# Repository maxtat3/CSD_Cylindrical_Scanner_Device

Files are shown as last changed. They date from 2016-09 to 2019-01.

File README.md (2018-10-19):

# Cylindrical Scanner Device (CSD)
This electronic-mechanical device for research of processes in the activation of surfaces by diffusion welding and soldering cylinder samples in a vacuum. It is used for scientific research.
Named: Cylindrical Scanner Device (CSD) or Surface Activation Scanner (SAC) .
You can [view photo](https://drive.google.com/folderview?id=0B9YGrJoTVMatWHJlU2hkQTU4MW8&usp=sharing) when debug this device.

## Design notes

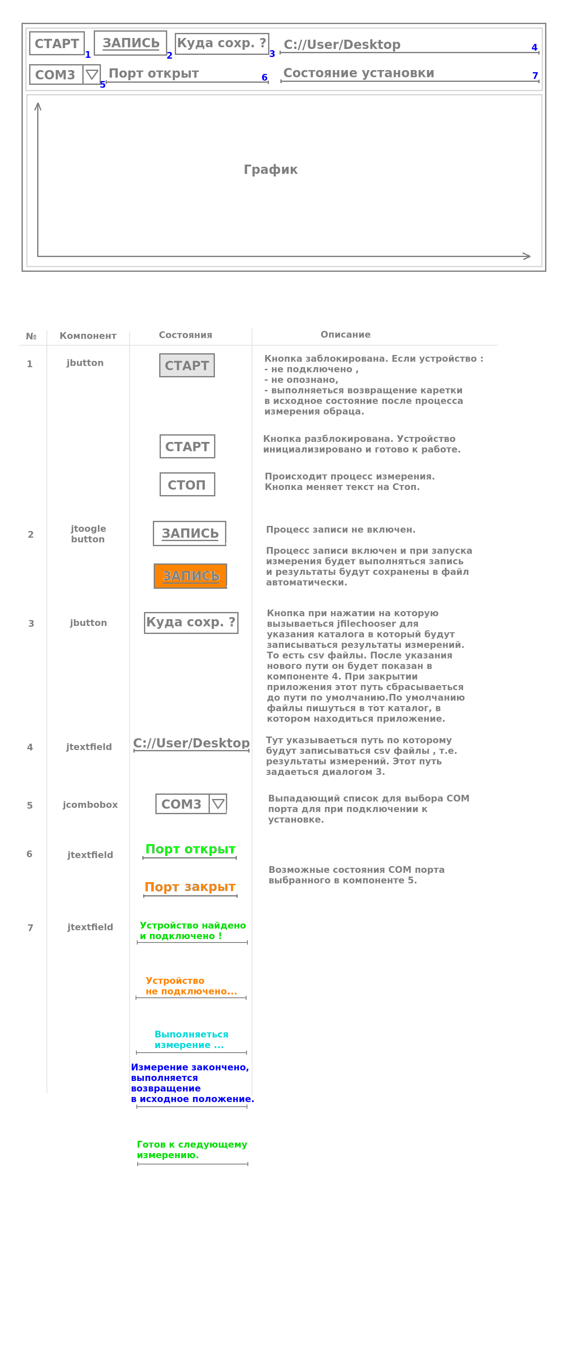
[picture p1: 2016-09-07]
etc/UI_mockup.png

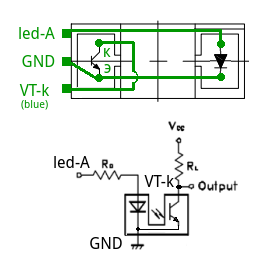
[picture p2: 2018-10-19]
etc/opto-interrupter.png

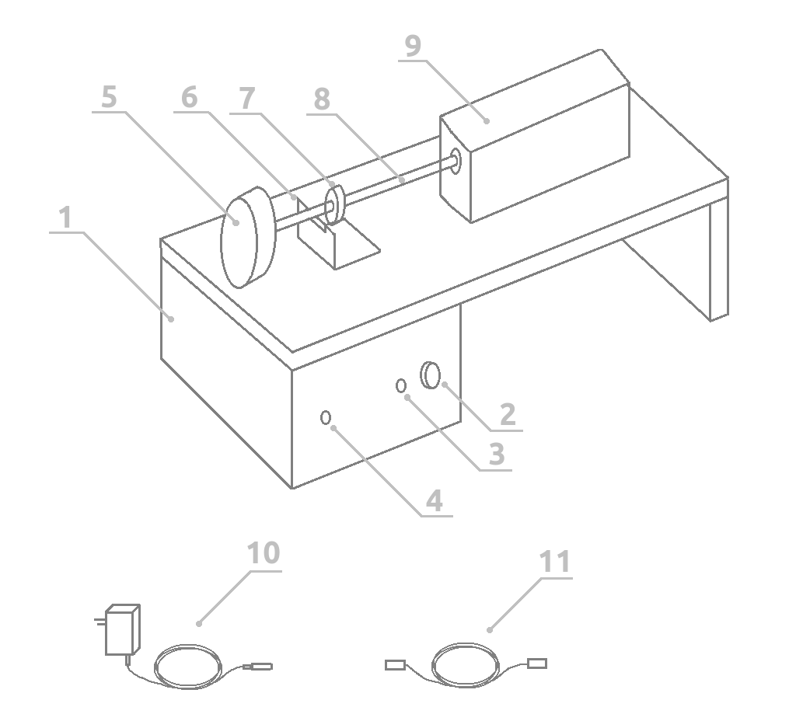
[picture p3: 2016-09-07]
etc/эскиз установки.png

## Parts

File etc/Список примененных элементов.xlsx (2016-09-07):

Идентификатор | Элемент | Корпус | Количество | Номинал | Цена за шт.(грн.) | Кол-во * шт (грн.)
1 | IC2 | TQFP32 | 1 | ATMEGA8A-AU | 35 | 35
2 | Q3,Q2,Q4,Q1 | to220_std | 4 | KT829 | 14 | 56
3 | D1,D2 | sod87 | 2 | 3V6 | 0.38 | 0.76
4 | RV2 | RV2 | 1 | 33k | 1.6 | 1.6
5 | RV1 | RV2 | 1 | 1k | 1.6 | 1.6
6 | RV3 | RV2 | 1 | 10k | 1.5 | 1.5
7 | R15,R14,R9,R16,R13,R12 | r_0805 | 6 | 510 | 0.1 | 0.6
8 | R17,R10,R2,R11 | r_0805 | 4 | 10k | 0.1 | 0.4
9 | R3 | r_0805 | 1 | 1.5k | 0.1 | 0.1
10 | R5,R4 | r_0805 | 2 | 68 | 0.1 | 0.2
11 | R6 | r_0805 | 1 | 300 | 0.1 | 0.1
12 | R8,R7 | r_0805 | 2 | 310 | 0.1 | 0.2
13 | R1 | r_0805 | 1 | 910 | 0.1 | 0.1
14 | P8 | PIN_ARRAY_5x1 | 1 | CONN_SM | 1 | 1
15 | P3 | PIN_ARRAY_4x1 | 1 | CONN_USB | 1 | 1
16 | P4 | pin_array_3x2 | 1 | CONN_ISP | 1 | 1
17 | K1 | PIN_ARRAY_3X1 | 1 | CONN_INPUT_OPTO_INT | 1 | 1
18 | P7 | PIN_ARRAY_2X1 | 1 | CONN_OUT_IND_PROC_LED | 1 | 1
19 | P2 | PIN_ARRAY_2X1 | 1 | CONN_SENSOR_SIGNAL_IN | 1 | 1
20 | P1 | PIN_ARRAY_2X1 | 1 | CONN_SENSOR_LED_POW | 1 | 1
21 | P6 | PIN_ARRAY_2X1 | 1 | CONN_BTN_START_STOP | 1 | 1
22 | P5 | PIN_ARRAY_2X1 | 1 | CONN_POWER | 1 | 1
23 | D6,D5,D4,D3 | do214aa | 4 | 1N4007 | 0.43 | 1.72
24 | D7 | DO-214AC(SMA) | 1 | 1N5817 | 1.05 | 1.05
25 | IC1 | DIP-20__300_ELL | 1 | ATTINY2313-P | 30 | 30
26 | U1 | DIP-14__300_ELL | 1 | LM324N | 5 | 5
27 | X2 | crystal_hc-49s | 1 | 14.7456MHz | 9 | 9
28 | X1 | crystal_hc-49s | 1 | 12MHz | 4.15 | 4.15
29 | C9,C8,C1,C2 | c_0805 | 4 | 22pF | 0.1 | 0.4
30 | C10,C4,C7,C6,C5,C11,C16,C12,C13 | c_0805 | 9 | 0.1uF | 0.1 | 0.9
31 | C3 | c_0805 | 1 | 0.01uF | 0.1 | 0.1
32 | C14 | C1V5 | 1 | 470uFx10V | 7.5 | 7.5
33 | C15 | C1V5 | 1 | 22uFx10V | 0.2 | 0.2
34 | D8 | LED-5MM | 1 | LED-Y | 1.15 | 1.15
35 | Гнздо USB type B на плату | type B | 1 |  | 20 | 20
36 | Корпус EC410C4 100х100х50 , IP56 | EC410C4 | 1 |  | 55 | 55
37 | Кнопка тактовая на корпус | mount to case | 1 |  | 9 | 9
38 | Гнездо для питания на корпус | mount to case | 1 |  | 7 | 7
39 | Двигатель шаговый |  | 1 |  | 100 | 100
40 | Плата текстолита 100х80 |  | 1 |  | 20 | 20
41 | Переходник usb — rs232 CH340 | USB type A to DB9 | 1 |  | 80 | 80
42 | Источник питания 5В, 500 mA |  | 1 |  | 70 | 70
43 | Фототранзистор BPW17N | pinouts | 1 |  | 12 | 12
44 | Светодиод белый | pinouts | 1 |  | 3 | 3
45 | Опто прерыватель (датчик остановки) | DIP4 | 1 |  | 25 | 25
46 | Кабель USB type A 1,5 м | type A | 1 |  | 30 | 30
 |  |  |  |  | ОБЩАЯ СУММА = | 599.33

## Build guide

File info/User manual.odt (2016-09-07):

В.А. Кушнир, В.С. Макаренко, М.А. Татаренко

Руководство по эксплуатации прибора для исследования процессов при активации поверхностей при диффузионной сварке и

пайке в вакууме

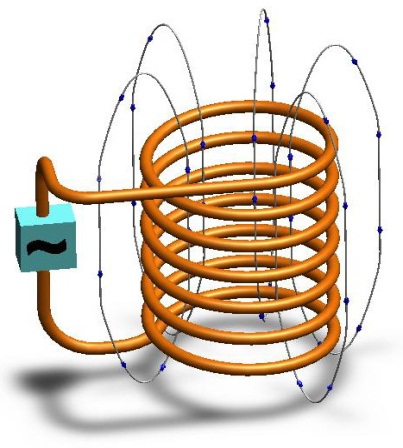
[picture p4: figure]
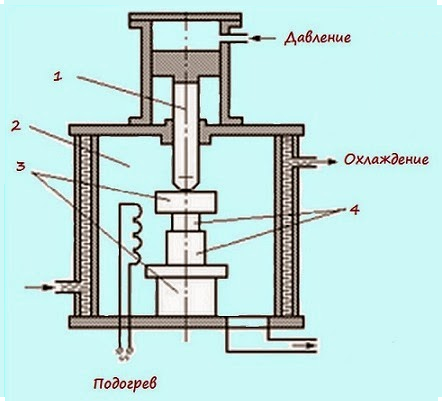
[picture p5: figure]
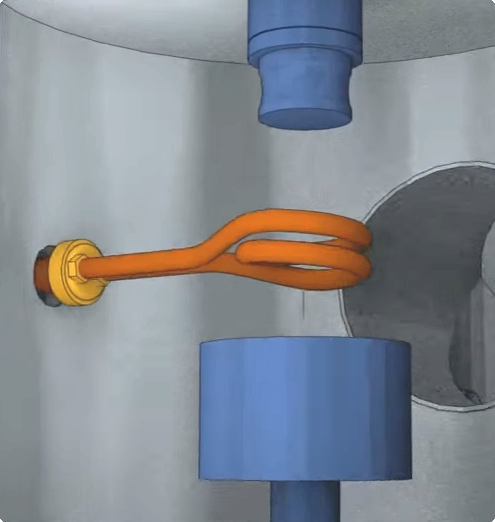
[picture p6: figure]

Содержание:

1. Технические характеристики

2. Составные части прибора

3. Структурная схема прибора и назначение блоков

4. Методика исследований и работы на приборе

1. Технические характеристики

Длина Х ширина Х высота устройства (мм) ……….……. ____ Х ____ Х ____

Длина Х ширина Х высота блока управления (мм) …... ____ Х ____ Х ____

Максимальный диаметр образца (мм) …………………………..…… 12 - 14

Максимальная длина образца (мм) ……………………………...………… 70

Напряжение питания блока управления (В) ………………….……….…… 5

Максимальный потребляемый ток (мА) ………………….…………….… 250

Тип применяемого кабеля для соединения с ПК ….. USB type A to type B

Протокол передачи данных ………………………………………..………. USB

Градиент освещения образца (%) ………………………………..… 0 — 100 %

Разрешающая способность АЦП (бит) ………………………………….…… 8

Количество выборок АЦП при полном цикле измерения ………….… 285

Погрешность измерений (%) ……………………………………….….…. 5 - 10

Время полного цикла одного измерения (с) ……………………….….….. 30

Время возвращения в исходное положение (с) …………….…….…...….. 25

Возможность запуска/остановки процесса измерений ____ с блока прибора и из программы ПК

2. Составные части прибора

На рис. 1 , 2, 3 показан внешний вид прибора с разных ракурсов. Прибор состоит из таких основных частей: блока управление и механической части.

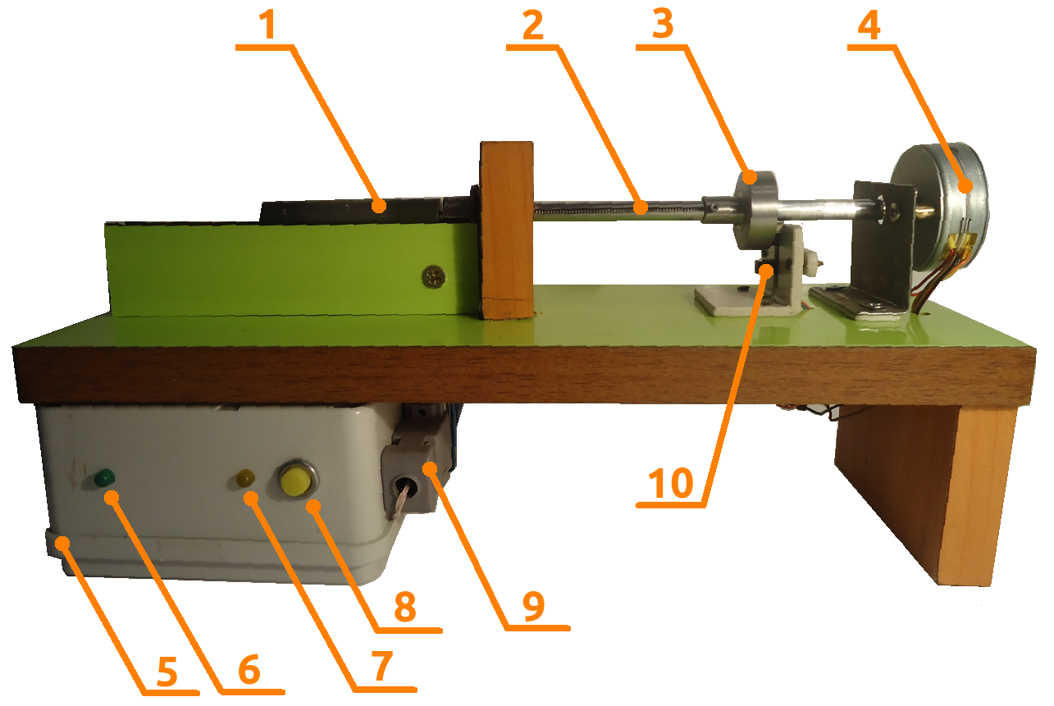
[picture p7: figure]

Рис 1

1 - образец, 2 - червяк для движения каретки с образцом, 3 - прерыватель для определения начального положения каретки, 4 - шаговый двигатель, 5 - блок управления, 6 - индикатор питания, 7 - индикатор процесса измерений, 8 - кнопка запуска/остановки процесса измерений, 9 - штекер для подключения к ПК, 10 - датчик для определения начального положения каретки , 11 - USB кабель для подключения к ПК, 12 - система из светодиода и фото-транизистора, 13 - клемники подключения светодиода и фото-транзистора, 14 — тубус для загрузки образца

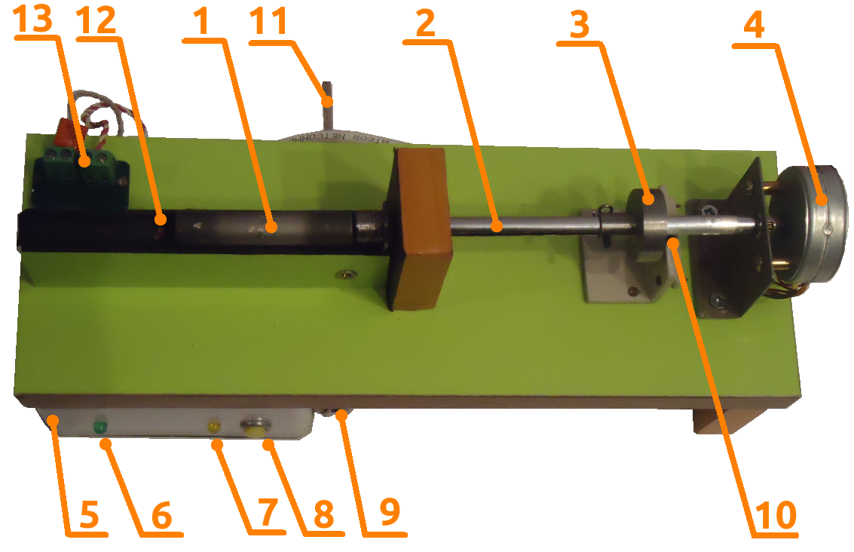
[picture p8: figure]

Рис 2

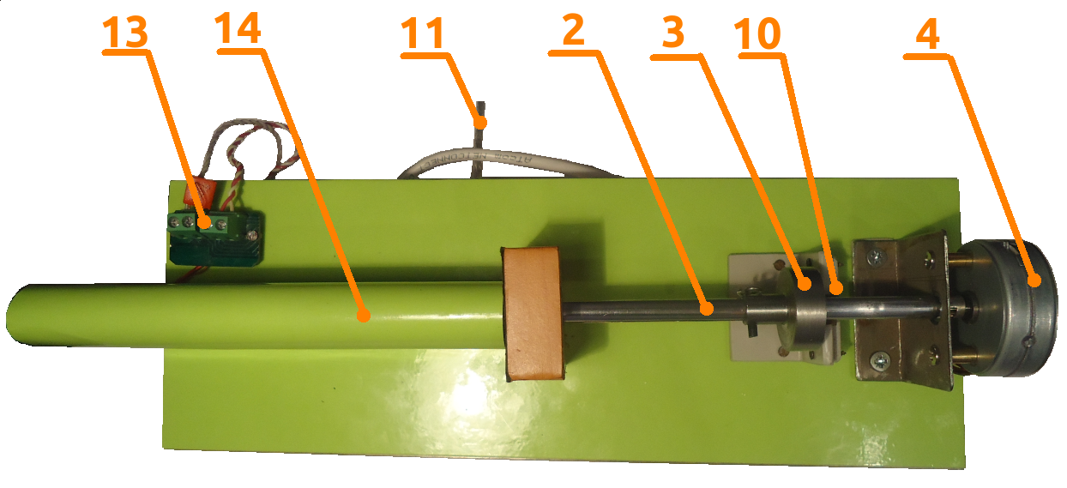
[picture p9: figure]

Рис 3

1 - образец, 2 - червяк для движения каретки с образцом, 3 - прерыватель для определения начального положения каретки, 4 - шаговый двигатель, 5 - блок управления, 6 - индикатор питания, 7 - индикатор процесса измерений, 8 - кнопка запуска/остановки процесса измерений, 9 - штекер для подключения к ПК, 10 - датчик для определения начального положения каретки , 11 - USB кабель для подключения к ПК, 12 - система из светодиода и фото-транизистора, 13 - клемники подключения светодиода и фото-транзистора, 14 — тубус для загрузки образца

Рис. 1, 2, 3 Фотографии прибора и его основные составляющие

На рис. 4 представлен внешний вид и схематическое отображение основных элементов основного блока прибора с фронтальной и тыльной стороны.

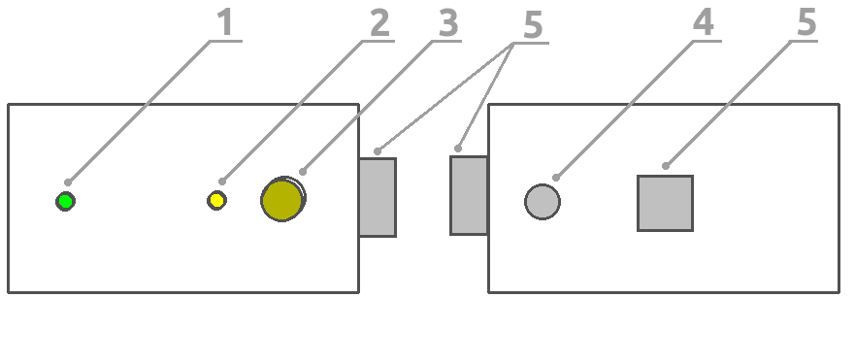
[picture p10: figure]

Рис. 4

1 - индикатор питания, 2 - индикатор процесса измерений, 3 - кнопка запуска/остановки процесса измерений, 4 — гнездо для подключения адаптера питания , 5 — гнездо для подключения кабеля для работы прибора с ПК.

Рис. 4 Внешний вид основного блока п с фронтальной (слева) и тыльной (справа) стороны

3. Структурная схема прибора и назначение блоков

Прибор состоит из структурных блоков и электрической схемы. Структурная схема работы прибора приведена на рис. 5

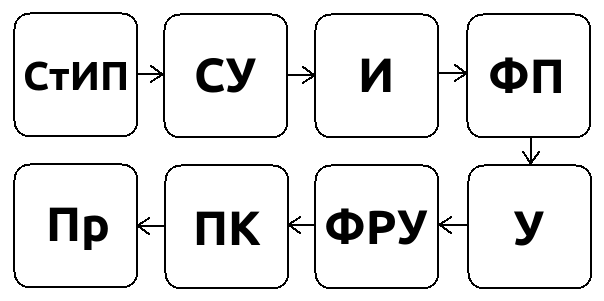
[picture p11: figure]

Рис. 5 Структурная схема работы прибора для исследований активации поверхности

Структурная схема работы прибора состоит из:

1. Стабилизированый источник питания (СтИП) — является источником питания для прибора;
2. Сканирующее устройство (СУ) предназначено для получения информации о поверхности образца о степени её диссоциации. Включает в себя датчик движения, шаговый двигатель и преобразователь вращательного движения в поступательное;
3. Излучатель (И) представляет собой источник постоянного светового потока (светодиод);
4. Фотоприемник (ФП) - представляет собой фото-преобразователь с внутренним фотоэффектом и служит для преобразования отраженного светового потока в фото-ЭДС;
5. Усилитель (У) — предназначен для усиления уровня напряжения до уровня работы АЦП (аналогово-цифрового преобразователя), который является составной частью микроконтроллера;
6. Фото-регеструющее устройство (ФРУ) - представляет собой блок связи с компьютером, также преобразует аналоговый сигнал усилителя в цифровой, обрабатывает его, включая и выключая шаговый двигатель, определяет количество шагов шагового двигателя;
7. Персональный компьютер (ПК) служит для визуального отображения результатов измерений и управления прибором;
8. Программа (Пр) - предназначена для записи, обработки данных , преобразования их в графический вид и управления прибором.

4. Методика исследований и работы на приборе

4.1 Включаем персональный компьютер (далее для краткости ПК) и устанавливаем (инсталлируем) необходимое программное обеспечение (далее для краткости ПО). Как установить см. в Приложении 1 технической документации;

4.2 Подключаем usb кабель одним концом к прибору , другим к ПК ;

4.3 Подключаем штекер сетевого адаптера к прибору. Включаем адаптер в сеть 220 В ; После этого должен включиться зелёный светодиодный индикатор (рис. 1 поз 6) ;

4.4 Запускаем ПО (исполняемую программу DetermChromeDevice v1.1) на ПК . Если после запуска ПО появилось сообщение об ошибке «Не удаётся найти устройство» то см Приложение 3 технической документации.

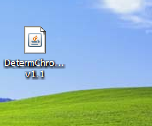
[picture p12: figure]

Рис. 6 Значок программы на рабочем столе

4.5. Для начала измерений вставляем образец в тубус (рис. 1 , поз. 1) до упора. Нажимаем на кнопку «Старт/Стоп» (рис. 1 , поз. 8) на блоке устройства (рис. 1 , поз. 5) или в программе. После этого шаговый двигатель (далее для краткости ШД) (рис. 1 , поз. 4) начинает вращение в прямом направлении, двигая образец поступательно, а также должен включиться жёлтый светодиод (рис.1, поз. 7) индицирующий сам процесс измерений. После этого в программе на ПК должен динамически строиться график. На этом графике по оси абсцисс — длина образца в мм , по оси ординат — напряжение светотока в мВ. Полный цикл измерений одного образца длиться примерно 30 секунд.

Если процесс измерений по каким либо причинам нужно остановить не дожидаясь завершения, это можно сделать в любой момент нажав ещё раз на кнопку «Старт/Стоп» на блоке управления или в программе.

В не зависимости был выполнен полный цикл измерений или измерения прекращены в какой-то момент времени — график должен отображаться в программе.

4.6. После окончания измерений, ШД начинает движение в обратном направлении , возвращая каретку для перемещения образца в исходное положение. То есть образец перемещается вдоль сканирующего устройства, а данные обрабатываются в реальном времени и строится график на дисплее ПК. При этом кнопка Старт/Стоп в программе будет заблокирована на время завершения возвращения в исходное положение. Требуемое время для этого примерно 25 секунд. Исходное положение определяется датчиком положения (рис. 1 , поз. 3, 10) . Когда исходное положение будет достигнуто - выключиться индикатор (рис. 1 , поз. 7) .

Для записи результатов измерений в файл в программе на ПК должен быть установлен переключатель «Запись» . Полученный график после завершения измерения будет сохранен в файл автоматически. Имя файла соответствует дате и времени получения результатов. Пример названия файла и его формат: 05_01_2016__22_49_15.csv.

Рис. 7 Сохраненный файл результатов измерения отражательной способности поверхности

Этот файл можно открыть для дальнейшего исследования в любом редакторе, например Microsoft Excel, MathCad, MathLab , и т. д. .

Для запуска нового измерения снова загружаем образец в тубус и нажимаем на кнопку «Старт/Стоп». Начнётся новый процесс. Предыдущий график в окне программы будет очищен и начнёт строиться новый. Дальнейшие шаги аналогичны .

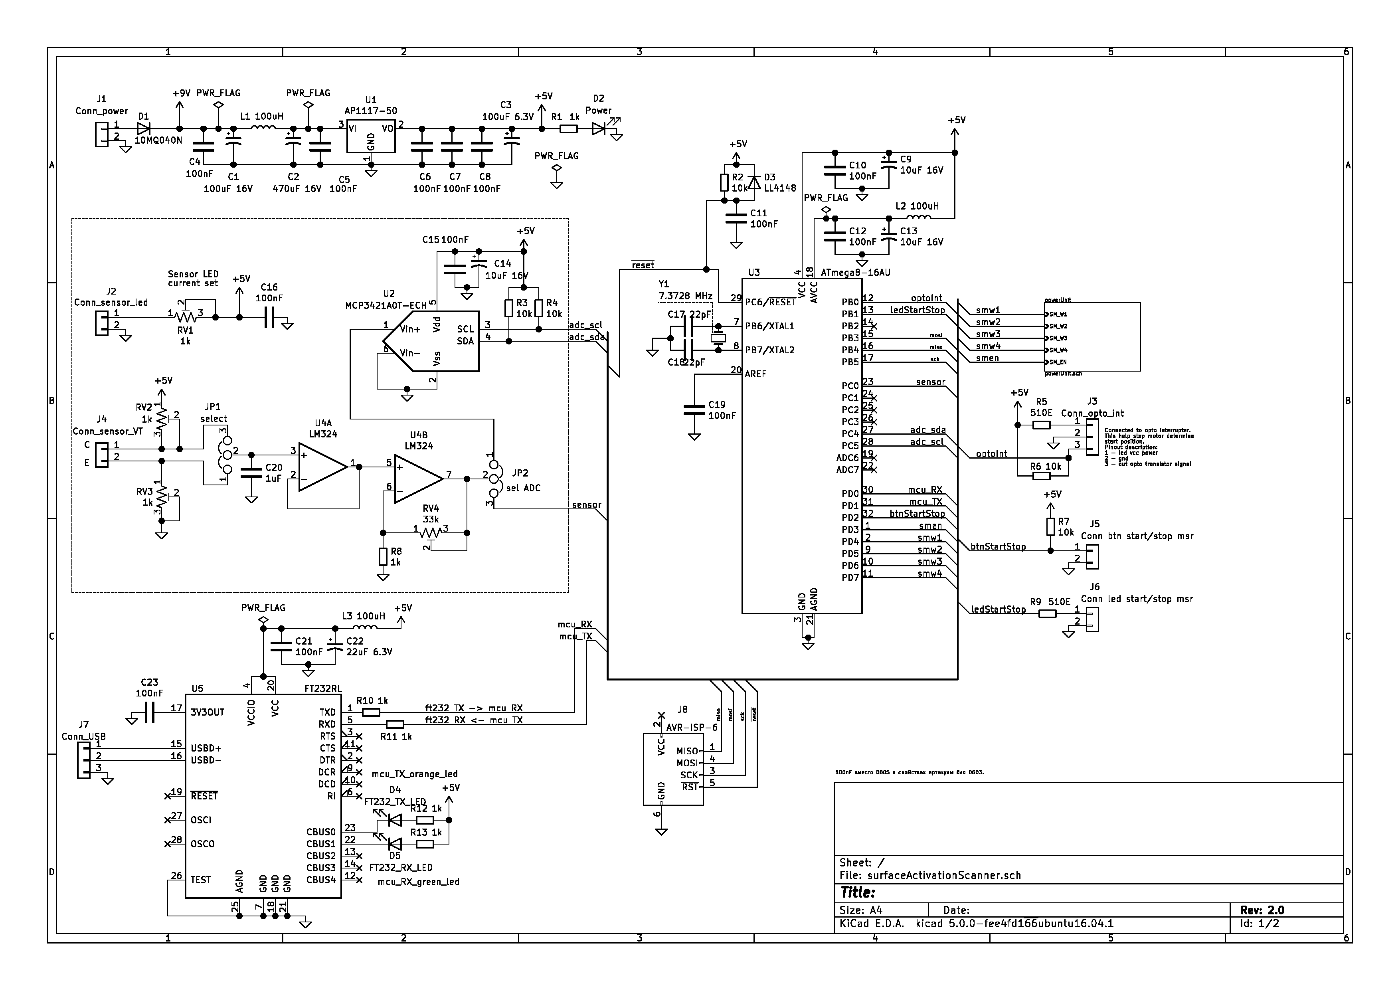
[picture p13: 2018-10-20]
circuit/print/surfaceActivationScanner.png

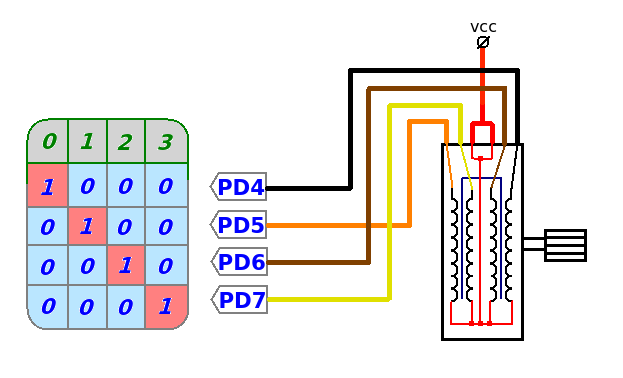
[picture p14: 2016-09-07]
etc/step_motor_connections.png

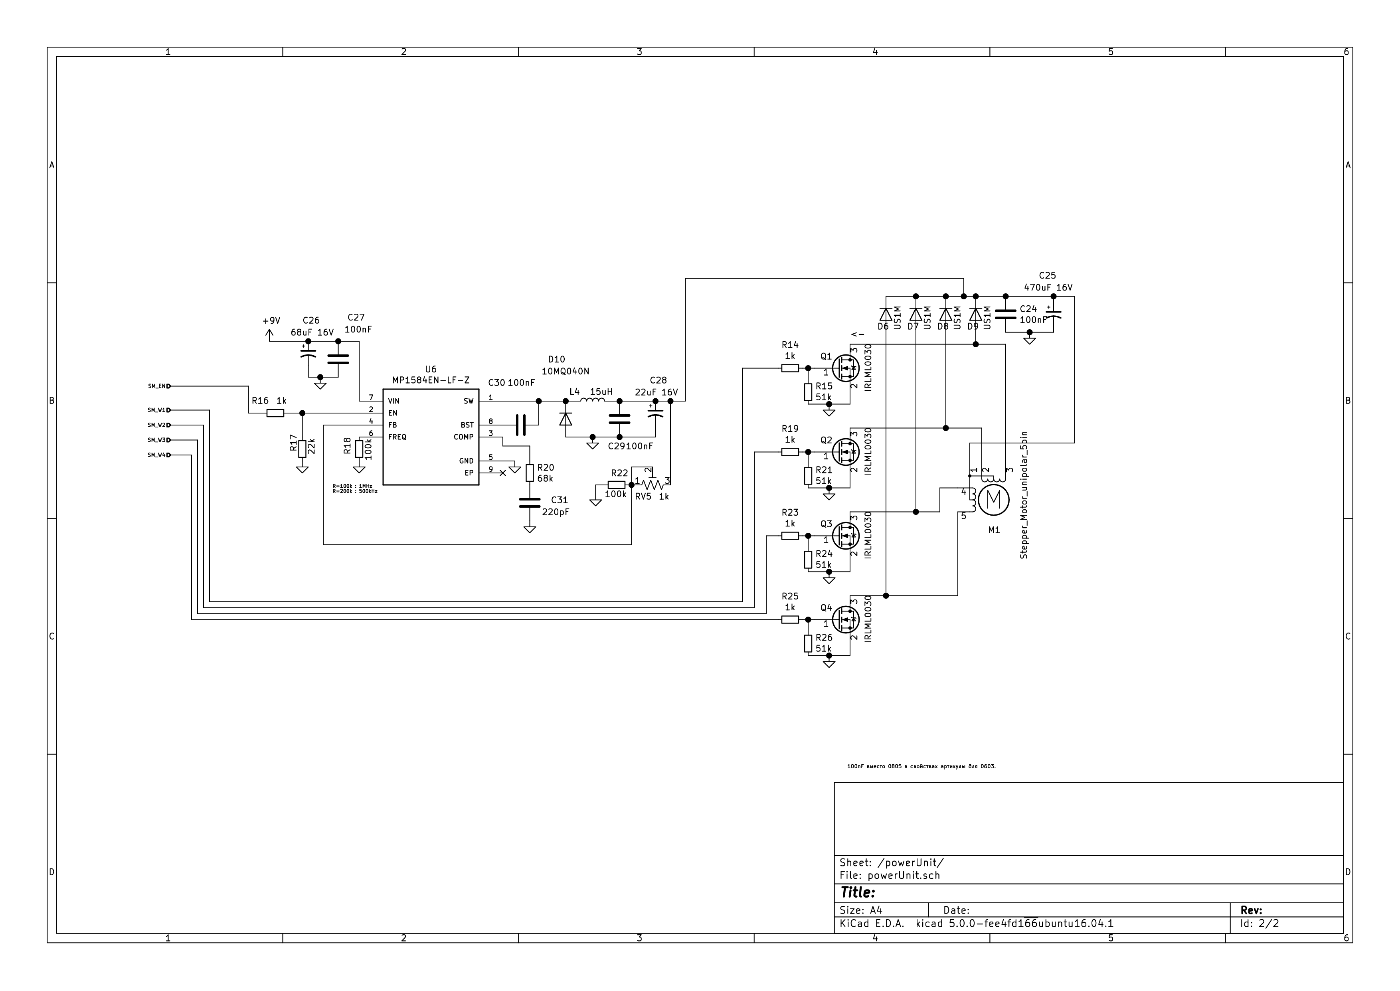
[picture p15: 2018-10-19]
circuit/print/powerUnit-powerUnit.png

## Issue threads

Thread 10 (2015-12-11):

Изменить координаты на графике

maxtat3, 2015-12-11:
Текущие координаты x (кол-во точек) и y (разрядность) на графике привести к координатам предметной области. x - проценты освещения 0 ... 100 (%) ; у - длина образца 0 ... 55 (мм) .

maxtat3, 2015-12-16:
По оси y должны быть мВ. Максимально значение = несколько сто мВ.

Closed 2015-12-16.

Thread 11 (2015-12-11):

Попробовать сделать циклический перебор com портов.

maxtat3, 2015-12-11:
Например чтобы не нужно было указывать его вручную при первом включении устройства.  Из списка поочередно выбирается номер ком порта и выполняется попытка подключения. Если подключение не удалось (порт закрыт) то переход к след порту. И так пока не получиться подключиться до конца списка JComboBox . Если в списке порты закончились - выдать messehe dialog "не удалось подключение !" .

Closed 2015-12-15.

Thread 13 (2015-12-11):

Увеличить скорость шд при возвращении в исходное положение

maxtat3, 2015-12-11:

maxtat3, 2015-12-15:
Увеличена скорость вращения в обратном направлении на 33 % . Для этого уменьшено время срабатывания TCNT1 на 3.3 ms .
13.3 ms = прямой ход
10.0 ms = обратный ход

Closed 2015-12-15.

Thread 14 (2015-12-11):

Сделать сохранение в конфиг файле последнего открытого com порта

maxtat3, 2015-12-11:
Это нужно что бы каждый раз при последующих запусках приложения не устанавливать его по новой. Сохранение может быть реализовано в домашний каталог пользователя в скрытый файл.  Можно для этого сделать определение какая ОС установлена и на основании этого сохранять  в определенный каталог . Например для этого переменить properties файлы .

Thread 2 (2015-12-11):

Не всегда с первого раза выполняется инициализация com порта

maxtat3, 2015-12-11:

maxtat3, 2015-12-16:
Возможно это было связано с тем что ШД  возвращал каретку в  исходное положение и в это время была нажата кнопка Старт. Соответственно ничего не произошло - новое измерение не было запущено.

Closed 2015-12-16.

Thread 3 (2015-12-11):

График должен поместиться в одно окно приложения

maxtat3, 2015-12-11:
После запуска измерений график динамически рисуется в одном окне , но если точек более 250 тогда график начинает смещаться влево. Таким образом на экране отображаться только ~ 200 ... 250 точек в один момент времени.

maxtat3, 2015-12-16:
Для этого нужное количество точек , отображаемое на одном экране нужно задать в конструкторе new Trace2DLtd(amount_of_points).

Closed 2015-12-16.

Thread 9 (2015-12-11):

Весь текст крупным шрифтом и на русском

maxtat3, 2015-12-11:

maxtat3, 2018-12-13:
See:
afafdebf99510da37be68714a7c3424bee076bf0
3e1989139d28d78abb8eac634467cee6fbb667d4
5a35b6786f0f7b680f7ce03f5a2ecd85216bd477
9dc05716a6e57e19c2ebf4aa135b75ff24d63a95
d16e6a0ac646c74dc6d377b0455455cbefc3aa0d
a949742157e4fcbab432ff396b1378a2d09f3b0d

Closed 2018-12-13.

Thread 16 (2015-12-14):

Проверить корректность временных интервалов выводимых на графике

maxtat3, 2015-12-14:
Для этого на устройство можно подать сигнал с одинаково меняющейся периодичностью. Например меандр с частотой 1 или 2 Гц. А также можно сделать запись получаемого сигнала на стороне приложения, открыть в libre office calc, построить график и посмотреть равномерность временных интервалов .

maxtat3, 2015-12-15:
Генератор меандра выполнен на 8 разрядном ТС2 и написан в основном коде программы для мк.   Формирование меандра выполняется в прерывании таймера.  Меандр подается на вход ацп к  которому должен быть подключен датчик освещенности. Результаты проверки  временных интервалов была выполнена на разных ОС:
linux ubuntu 14.04 64 bit / jre7, jre8 -- график меандра ровный без заметных искажений, редко возникает незначительная погрешность +-5% ;
windows xp 32 bit / jre8 -- график меандра достаточно ровный без заметных искажений,  иногда есть незначительная погрешность примерно  +-5 ... +-10 % ;
windows 8 64 bit / jre8 -- иногда есть искажения, доходящие до погрешности примерно 25 % ;

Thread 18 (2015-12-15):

Изменить цвет курсора

maxtat3, 2015-12-15:
В linux цвет курсора на графике белый, а на ОС windows xp, 8 цвет черный. Поэтому его не видно. Попробовать поискать возможно ли изменить цвет курсора.

maxtat3, 2018-12-13:
Проверил на winxp jse 7 - курсор отображается корректно .

Closed 2018-12-13.

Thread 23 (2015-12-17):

Добавить текстовую надпись состояния установки

maxtat3, 2015-12-17:
В этой надписи ложны отображаться текстовая информация состояния установки и возможно приложения. Например "Выполняется измерения образца", "Возвращение в исходное положение".
Подумать что еще должно  быть ...

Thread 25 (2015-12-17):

Добавить возможность сохранять файлы в любой каталог.

maxtat3, 2015-12-17:
При включенной записи , по умолчанию файлы с результатами измерений записываются в тот же самый каталог , где расположена программа. Возможно сделать кнопку , при нажатии на которую открывается диалог выбора каталога где хранить файлы. То есть изменяется путь. А также добавить текстовое поле в котором отображается путь к каталогу куда будут писаться результаты.

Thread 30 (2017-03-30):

Большая погрешность измерений

maxtat3, 2017-03-30:
В процессе измерений выяснилось что в функции отображаемой при построении графика присутствует ошибка. Проявляется она как некий шум - зубцы вместо плавной линии на графике. Амплитуда этих зубцов примерно 9 mV свето-тока (максимальное значение шкалы 400 mV).

Возможные улучшения:
- В данном случае шкала свето-тока не соответствует разрядности АЦП:
400 mV / 256 = 1,56. То есть 1 квант АЦП = 1,56 mV свето-тока.
9 mV / 1,56 mV = [5...6] квантов АЦП. Тогда ошибка = +-3LSB.
Увеличить разрядность АЦП , хотя бы 10 бит, применив встроенный модуль в mcu; Также при этом нужно изменять протокол передачи данных pc <-> mcu .   Данные на ПК должны приниматься пачками по 2 Байта.  А еще лучше применить внешний 12 битный АЦП. Это должна быть отдельная МС.
- Задействовать внешний высокоточный ИОН , например на TL431, вместо встроенного в mcu;
- Возможно пересмотреть схему усилителя для фото транзистора. Сделать ее попроще;
- Помехи от драйвера ШД по питанию проникают в АЦП;
- Улучшение программ для ПК и МК;

maxtat3, 2018-10-19:
Выяснилось что на линии +5V есть высокочастотная помеха амплитудой ~200mV в состоянии ожидания. Частота >= несколько MHz. На выходе ОУ соответственно также есть помеха амплитудой ~35mV.

Проверенные возможные варианты:
* Питание платы от чистого источника в виде АКБ почти ничего не дало - незначительное снижение этой помехи;
* Отключение выносного интерфейсного преобразователя - незначительно снизило помеху примерно на 30...50 mV; Это возможно связано с работой преобразования USB->RS232(+-12V)->UART TTL(0-5V);
* Помеха незначительно увеличивается при выполнении измерений - работа ШД;

Плата выполнена по ЛУТ без земли на 2-м слое и со множеством навесных проводников (сигнальных и силовых) соединяющих различные части схемы.  В процессе наладки также было много пайки на этой плате - наладка входного усилителя от фото-диода, а затем фото-транзистора , а также замена интерфейсной МС ATtiny2313 на MAX232.
Из вышеприведенных фактов, а также из за некачественной трассировки силовых линий можно сделать вывод о очень вероятном появлении таких помех.

maxtat3, 2018-12-13:
Сделана новая версия платы.
Уровень помех по аналоговой части <= 2...3 mV .
See:
1a54fb2d37c044c67d34c5ec4351b448af90f632
bce4909661703198dcb44aeb876bf2b34da9bdd5

Closed 2018-12-13.

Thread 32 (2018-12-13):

Возможно нужно изменить коэффициент синхронизации АЦП !

maxtat3, 2018-12-13:
См stepAdcSyncConst = 17 по умолчанию.
Это связано с тем что при заданной длине образца 60 мм на графике по оси Х отображается ~56 мм и передается не 300 а 285 значений АЦП . При этом шаг между отправляемыми значениями = 0.2 мм и при прочих равных настройках .
Например при длине образца = 60 мм
60 / 0.2 = 300 значений АЦП.

Попробовать тестировать на значении = 16.

maxtat3, 2018-12-13:
Похоже что этот коэф. подходит. На графике отображается ~61 мм при передвижении каретки на полную длину образца и в терминале видно что передается 302 значения.
В этом случае погрешность составляет ~ 1%
See d70a2289c745658591504b7420ff3486812511d3

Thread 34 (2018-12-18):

Улучшение протокола обмена

maxtat3, 2018-12-18:
Это очень черновой вариант

package lsb:
Byte		desc
-----------
general rsp format
0				cmd
1,2			data (0,1)

csd #1 init
rq: n i 1
rsp: s c 1

pc request: 0, 0, 1 start msr
mcu response: [D1], [D0], 1

pc request: 0, 0, 2 stop msr
??? mcu response: 0, 0, 2

in uart module
send_pck(uint8_t d1, uint8_t d0, uint8_t cmd)
or
---//---(struct pck)

commands.h
#define START	0x01
stop 0x02
init 0x00

strucr{
	uint8_t cmd,
	 uint8_t d0, //data byte0
	 uint8_t d1 //data byte1
}pck

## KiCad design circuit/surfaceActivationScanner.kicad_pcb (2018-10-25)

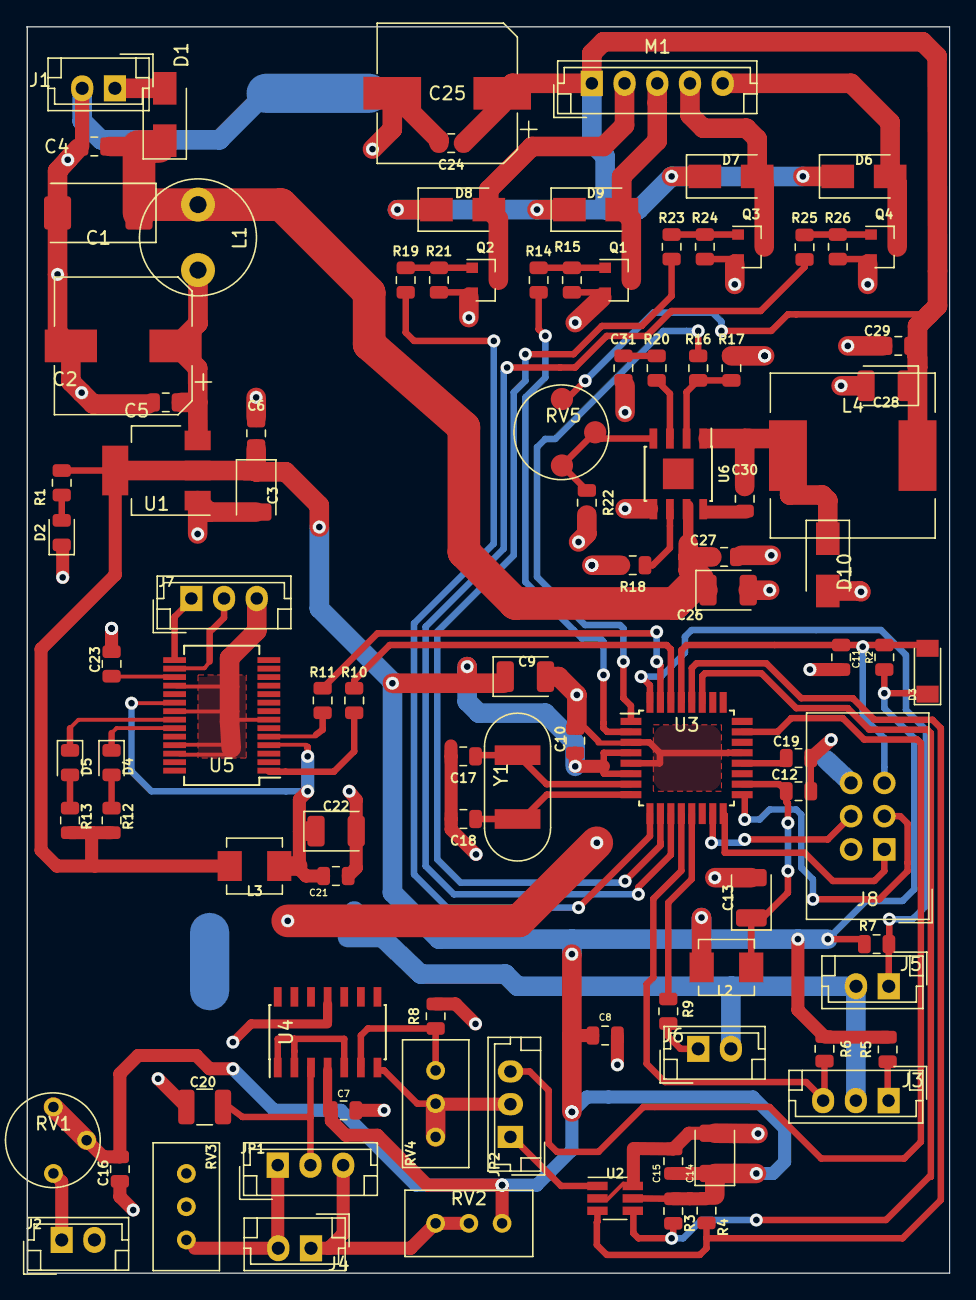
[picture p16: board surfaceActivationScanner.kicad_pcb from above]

Board: 2 copper layers, 70.5 x 95.3 mm, 98 parts (0 on the bottom side), 63 nets.

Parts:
C1: 100uF 16V; CP_EIA-7343-31_Kemet-D
C2: 470uF 16V; CP_Elec_10x10
C3: 100uF 6.3V; CP_EIA-3528-21_Kemet-B
C4, C5, C6, C7, C8, C10, C11, C12, C15, C16, C19, C21, C23, C24, C27, C29, C30: 100nF; C_0805_2012Metric
C9, C13, C14: 10uF 16V; CP_EIA-3528-21_Kemet-B
C17, C18: 22pF; C_0805_2012Metric
C20: 1uF; C_1210_3225Metric
C22: 22uF 6.3V; CP_EIA-3528-21_Kemet-B
C25: 470uF 16V; CP_Elec_10x12.5
C26: 68uF 16V; CP_EIA-3528-21_Kemet-B
C28: 22uF 16V; CP_EIA-3528-21_Kemet-B
C31: 220pF; C_0805_2012Metric
D1, D10: 10MQ040N; D_SMA
D2: Power; LED_0805_2012Metric
D3: LL4148; D_MiniMELF
D4: FT232_TX_LED; LED_0805_2012Metric
D5: FT232_RX_LED; LED_0805_2012Metric
D6, D7, D8, D9: US1M; D_SMA
J1: Conn_power; JST_EH_B02B-EH-A_1x02_P2.50mm_Vertical
J2: Conn_sensor_led; JST_EH_B02B-EH-A_1x02_P2.50mm_Vertical
J3: Conn_opto_int; JST_EH_B03B-EH-A_1x03_P2.50mm_Vertical
J4: Conn_sensor_VT; JST_EH_B02B-EH-A_1x02_P2.50mm_Vertical
J5: Conn btn start/stop msr; JST_EH_B02B-EH-A_1x02_P2.50mm_Vertical
J6: Conn led start/stop msr; JST_EH_B02B-EH-A_1x02_P2.50mm_Vertical
J7: Conn_USB; JST_EH_B03B-EH-A_1x03_P2.50mm_Vertical
J8: AVR-ISP-6; IDC-Header_2x03_P2.54mm_Vertical
JP1: select; JST_EH_B03B-EH-A_1x03_P2.50mm_Vertical
JP2: sel ADC; JST_EH_B03B-EH-A_1x03_P2.50mm_Vertical
L1: 100uH; L_Radial_D8.7mm_P5.00mm_Fastron_07HCP
L2, L3: 100uH; L_Vishay_IHLP-1616
L4: 15uH; L_12x12mm_H6mm
M1: Stepper_Motor_unipolar_5pin; JST_EH_B05B-EH-A_1x05_P2.50mm_Vertical
Q1, Q2, Q3, Q4: IRLML0030; SOT-23
R1, R8, R10, R11, R12, R13, R14, R16, R19, R23, R25: 1k; R_0805_2012Metric
R2, R3, R4, R6, R7: 10k; R_0805_2012Metric
R5, R9: 510E; R_0805_2012Metric
R15, R21, R24, R26: 51k; R_0805_2012Metric
R17: 22k; R_0805_2012Metric
R18, R22: 100k; R_0805_2012Metric
R20: 68k; R_0805_2012Metric
RV1, RV5: 1k; Potentiometer_Vishay_T7-YA_Single_Vertical
RV2, RV3: 1k; Potentiometer_Bourns_3296W_Vertical
RV4: 33k; Potentiometer_Bourns_3296W_Vertical
U1: AP1117-50; SOT-223-3_TabPin2
U2: MCP3421A0T-ECH; SOT-23-6_Handsoldering
U3: ATmega8-16AU; TQFP-32_7x7mm_P0.8mm
U4: LM324; SOIC-14_3.9x8.7mm_P1.27mm
U5: FT232RL; SSOP-28_5.3x10.2mm_P0.65mm
U6: MP1584EN-LF-Z; SOIC-8-1EP_3.9x4.9mm_P1.27mm_EP2.35x2.35mm
Y1: 7.3728 MHz; Crystal_HC49-U_Vertical

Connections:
+5V: C3.1, C6.1, C7.1, C8.1, C9.1, C10.1, C14.1, C15.1, C16.2, D3.1, L2.2, L3.2, R1.2, R2.1, R3.1, R4.1, R5.2, R6.1, R7.1, R12.1, R13.1, RV1.2, RV1.3, RV2.1, U1.2, U2.5, U3.4, U3.6, U4.4
+9V: C1.1, C4.1, C26.1, C27.1, D1.1, L1.1, U6.7
/adc_scl: R4.2, U2.3, U3.28
/adc_sda: R3.2, U2.4, U3.27
/btnStartStop: J5.1, R7.2, U3.32
/ledStartStop: R9.2, U3.13
/mcu_RX: R10.1, U3.30
/mcu_TX: R11.1, U3.31
/miso: J8.1, U3.16
/mosi: J8.4, U3.15
/optoInt: J3.3, R6.2, U3.12
/sck: J8.3, U3.17
/sensor: JP2.3, U3.23
/smen: R16.1, U3.1
/smw1: R14.2, U3.2
/smw2: R19.2, U3.9
/smw3: R23.2, U3.10
/smw4: R25.2, U3.11
/~reset: C11.1, D3.2, J8.5, R2.2, U3.29
GND: C1.2, C2.2, C3.2, C4.2, C5.2, C6.2, C7.2, C8.2, C9.2, C10.2, C11.2, C12.2, C13.2, C14.2, C15.2, C16.1, C17.2, C18.2, C19.2, C20.2, C21.2, C22.2, C23.2, C24.2, C25.2, C26.2, C27.2, C28.2, C29.2, C31.2, D2.1, D10.2, J1.2, J2.2, J3.2, J5.2, J6.2, J7.3, J8.6, Q1.2, Q2.2, Q3.2, Q4.2, R8.2, R15.1, R17.2, R18.2, R21.1, R22.2, R24.1, R26.1, RV3.2, RV3.3, U1.1, U2.2, U2.6, U3.3, U3.5, U3.21, U4.11, U5.7, U5.18, U5.21, U5.25, U5.26, U6.5
unnamed: C2.1, C5.1, L1.2, U1.3
unnamed: C12.1, C13.1, L2.1, U3.18
unnamed: C17.1, U3.7, Y1.2
unnamed: C18.1, U3.8, Y1.1
unnamed: C19.1, U3.20
unnamed: C20.1, JP1.2, U4.3
unnamed: C21.1, C22.1, L3.1, U5.4, U5.20
unnamed: C23.1, U5.17
unnamed: C24.1, C25.1, C28.1, C29.1, D6.1, D7.1, D8.1, D9.1, L4.2, M1.1, RV5.3
unnamed: C30.1, U6.8
unnamed: C30.2, D10.1, L4.1, U6.1
unnamed: C31.1, R20.2
unnamed: D1.2, J1.1
unnamed: D2.2, R1.1
unnamed: D4.1, U5.23
unnamed: D4.2, R12.2
unnamed: D5.1, U5.22
unnamed: D5.2, R13.2
unnamed: D6.2, M1.5, Q4.3
unnamed: D7.2, M1.4, Q3.3
unnamed: D8.2, M1.2, Q2.3
unnamed: D9.2, M1.3, Q1.3
unnamed: J2.1, RV1.1
unnamed: J3.1, R5.1
unnamed: J4.1, JP1.3, RV2.2, RV2.3
unnamed: J4.2, JP1.1, RV3.1
unnamed: J6.1, R9.1
unnamed: J7.1, U5.15
unnamed: J7.2, U5.16
unnamed: JP2.1, U2.1
unnamed: JP2.2, RV4.2, RV4.3, U4.7
unnamed: Q1.1, R14.1, R15.2
unnamed: Q2.1, R19.1, R21.2
unnamed: Q3.1, R23.1, R24.2
unnamed: Q4.1, R25.1, R26.2
unnamed: R8.1, RV4.1, U4.6
unnamed: R10.2, U5.1
unnamed: R11.2, U5.5
unnamed: R16.2, R17.1, U6.2
unnamed: R18.1, U6.6
unnamed: R20.1, U6.3
unnamed: R22.1, RV5.1, RV5.2, U6.4
unnamed: U4.1, U4.2, U4.5

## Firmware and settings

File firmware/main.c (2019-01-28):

#include <avr/io.h>
#include <util/delay.h>
#include <avr/interrupt.h>
#include <util/atomic.h>
#include <stdbool.h>
#include "bit_macros.h"
#include "uart.h"
#include "adc.h"
#include "indication.h"
#include "opto_interrupter.h"


// ==========================================
// 			Шаговый двигатель
// ==========================================
/* Определение регистров порта к которму подключен шаговый двигатель (ШД) */
#define		SM_PORT		PORTD		
#define		SM_PIN		PIND
#define		SM_DDR		DDRD

/* Определения номера порта для включения DC-DC преобразователя - ИП для ШД */
#define		SM_EN	3

/* определения номеров портов к котрым подключены обмотки ШД */
#define		SM_WIRE_1	4
#define		SM_WIRE_2	5
#define		SM_WIRE_3	6
#define		SM_WIRE_4	7

// ==========================================
// 			Настройки ТС1, отвечающего за
//			вращение ШД
// ==========================================
/* Начальное значение регистра TCNT1, выбираеться в зависимости от скорости  вращения ШД */
#define 	TCNT1_SM_FORVARD_MOVE		64000 // срабатывание каждые ~ 13.3 ms
#define 	TCNT1_SM_REVERSE_MOVE		64380 // срабатывание каждые ~ 10.0 ms

/* Максимальное количество шагов в одном направлении. Зависит от длины максимального перемещения ротора в одном направлении */
// #define		SM_MAX_PROGREESS	300

// ==========================================
// 			Другие макросы
// ==========================================
/* Количество полных поворотов ротора ШД для перемещения каретки в червячной передачи на 1 см */
#define 	SM_FULL_ONE_ROTATE_1CM	9

/* Количество шагов ротора ШД при полном обороте на 360 град. (нормальный шаг)*/
#define 	SM_ONEROTATE_360_DEGR	95

/* Полная длина (см) на которую перемещаеться каретка, достаточная для полного измерения образца */
#define 	FULL_LENGTH_CM			6

/* Вычисление количества шагов ШД для перемещения каретки в червячной передачи на полную длину , при выполнении измерений образца */
#define		SM_FULL_MSR_STEPS		SM_FULL_ONE_ROTATE_1CM * SM_ONEROTATE_360_DEGR * FULL_LENGTH_CM


/* задержка между каждым шагом при врещении ШД, это определяет скорсть вращения. Используеться только для парковки в нач состояние ШД */
#define		SM_DELAY_STEP_MS	5

/* Задержка между данными и командой при отправке в COM порт */
// #define		USART_CMD_OR_DATA_DELAY	2	// not used ?


/* Выполнен ли захват ТС1, т.е. включен он (ШД вращаеться) или нет. false - ТС1 свободен (выключен), ШД остановлен; true - ТС1 включен, ШД выполняет вращение */
volatile bool isBlockTC1 = false;

// запоминае состояние состояния кнопки запуска/остановки процееса измерений
volatile bool btnStateFlag = false;




// таблица шагов ШД , нормальный шаг
// const char smTableNormalStep[] = {_BV(SM_WIRE_1), _BV(SM_WIRE_2), _BV(SM_WIRE_3), _BV(SM_WIRE_4)};
const int8_t smTableNormalStep[] = {_BV(SM_WIRE_4), _BV(SM_WIRE_3), _BV(SM_WIRE_2), _BV(SM_WIRE_1)};



/* Command codes */
/** Запуск измерений **/
#define		CMD_MAKING_MSR		1

/** Остановка измерений **/
#define		CMD_STOP_MSR		2

/** Выполняетс парковка в начальное положение **/
#define 	CMD_MAKING_PARKING	3

/** Парковка в начальное положение закончена **/
#define 	CMD_STOP_PARKING	4

/** Идентефикация этого устройства на выбранном COM порту **/
#define 	CMD_INIT_DEVICE		5
const char DATA_RIGHT_INIT_DEVICE[] = {'C', 'S', 'D'};


/* Перечислегние команд от ПК */
enum fromPcCommands{
	STDBY,
	DO_START_SM,
	DO_STOP_SM
};
volatile enum fromPcCommands pcCommand = STDBY;



static uint8_t rxBuff[RX_BUFF_SIZE];
static uint8_t cmd = 0;
static uint32_t data = 0;

static uint8_t txPckBuff[TX_BUFF_SIZE];


/** Формирование RSP пакта без данных для отправки на сервер **/
void codingRspPck0(uint8_t cmd);

/** Формирование RSP пакта с 1-м Байтом данных для отправки на сервер **/
void codingRspPck8(uint8_t data, uint8_t cmd);

/** Формирование RSP пакта с 2-я Байтами данных для отправки на сервер **/
void codingRspPck16(uint16_t data, uint8_t cmd);

/** Формирование RSP пакта с 3-я Байтами данных для отправки на сервер **/
void codingRspPck32(uint32_t data, uint8_t cmd);

void initIO(void);


void initExtInt0(void);
void initTC2(void);
// void initTC0(void);	// todo - not used ? 
void turnOnTC1(void);
void turnOffTC1(void);

bool checkSMInBeginPos(void);
void stopSM(void);


int main(void){
	cli();
	initIO();
	initUSART();
	initADC();
	// initExtInt0();
	// initTC2();
	init_ind_led_msr();
	init_opto_interrupter();
	sei();

	checkSMInBeginPos();

	start_cont_conv();


	while(1){
		getPckOfUART(rxBuff);

		cmd = (uint8_t)rxBuff[0] & 0xFF;

		if (cmd == CMD_INIT_DEVICE){
			uint8_t rsp[TX_BUFF_SIZE];
			rsp[0] = CMD_INIT_DEVICE;
			for (uint8_t i = 1; i < TX_BUFF_SIZE; ++i){
				rsp[i] = DATA_RIGHT_INIT_DEVICE[i-1];
			}
			sendPckToUART(rsp);

		} else if (cmd == CMD_MAKING_MSR){
			pcCommand = DO_START_SM;

		} else if(cmd == CMD_STOP_MSR){
			pcCommand = DO_STOP_SM;

		}


		switch(pcCommand){
			case STDBY:
				break;

			case DO_START_SM:
				if (isBlockTC1 == false){
					cli();
					turnOnTC1();
					sei();
				}
				break;

			case DO_STOP_SM:
				btnStateFlag = false;
				break;
		}

	}
}




// Обработчик кнопка для запуска/остановки процееса измерений
ISR(INT0_vect){
	// start measuring
	if (btnStateFlag == false){
		btnStateFlag = true;
		pcCommand = DO_START_SM;
	// stop measuring
	} else if (btnStateFlag == true){
		btnStateFlag = false;
		pcCommand = DO_STOP_SM;
	}

	_delay_ms(200); // антидребизг
}


// константа определяющая количество шагов которое нужно пропустить 
// прежде чем отправить значение ацп с датчика освещенности.
// Это нужно для синхронизации количества шагов с еденицами измерения длины образца в мм.
// 95 * 9 = 855 - перемещение каретки на 1 см.  См. SM_FULL_ONE_ROTATE_1CM SM_ONEROTATE_360_DEGR
// Округлим это значение до 850, т.к. полученные данные приблеженные. 
// Далее 10 мм делим на 0.2 мм = 50 раз. В 50 раз нужно уменьшить полученное число шагов. 
// Т.е. 850 делим на 50 = 17 шагов нужно для перемещения червяка на 0.2 мм. 
// Это приблеженное значение т.к. SM_FULL_ONE_ROTATE_1CM SM_ONEROTATE_360_DEGR требуют калибровки!
const uint8_t stepAdcSyncConst = 16;

ISR(TIMER1_OVF_vect){
	// в каком направлении выполняеться движение ШД
	// false - прямое ; true - обратное
	static bool isDisableForward = false;
	// счетчик состяний обмоток ШД
	static int8_t stepCount = 0;
	// счетчик шагов ШД в процессе измерения
	static int16_t smProgressCount = 0;
	static uint8_t stepAdcSyncCount = 0;

	// прямой ход ШД - выполнение измерений
	if(smProgressCount < SM_FULL_MSR_STEPS && !isDisableForward){
		if (pcCommand == DO_START_SM){
			ind_led_msr_state(true, false, 0);

			SM_PORT = smTableNormalStep[stepCount] | _BV(SM_EN);
			stepCount ++;
			if (stepCount > 3) stepCount = 0;

			if (stepAdcSyncCount == stepAdcSyncConst){
				codingRspPck8((uint8_t)(get_adc_res()/4), CMD_MAKING_MSR);
				sendPckToUART(txPckBuff);
				stepAdcSyncCount = 0;
			} else {
				stepAdcSyncCount ++;
			}

			smProgressCount ++;

		}else if (pcCommand == DO_STOP_SM){
			isDisableForward = true;
			stepCount = 3;
			codingRspPck0(CMD_MAKING_PARKING);
			sendPckToUART(txPckBuff);
		}
	}else if(!isDisableForward){
		isDisableForward = true;
		stepCount = 3;
		codingRspPck0(CMD_MAKING_PARKING);
		sendPckToUART(txPckBuff);
		_delay_ms(300);
	}

	// обратный ход ШД - возвращение в исходное положение
	if (smProgressCount > 0 && isDisableForward){
		SM_PORT = smTableNormalStep[stepCount] | _BV(SM_EN);
		stepCount --;
		if (stepCount < 0) stepCount = 3;

		smProgressCount --;

		ind_led_msr_state(true, true, LED_BLINK_MEDIUM);
	}

	// останока ШД
	if (smProgressCount == 0 && isDisableForward){
		isDisableForward = false;
		stepCount = 0;
		smProgressCount = 0;
		turnOffTC1();
		ind_led_msr_state(false, false, 0);
		codingRspPck0(CMD_STOP_PARKING);
		sendPckToUART(txPckBuff);
	}

	if (!isDisableForward){
		TCNT1 = TCNT1_SM_FORVARD_MOVE;
	} else {
		TCNT1 = TCNT1_SM_REVERSE_MOVE;
	}
}


void codingRspPck0(uint8_t cmd) {
	*(txPckBuff) = cmd & 0xFF;
	*(txPckBuff+1) = 0;
	*(txPckBuff+2) = 0;
	*(txPckBuff+3) = 0;
}

void codingRspPck8(uint8_t data, uint8_t cmd) {
	*(txPckBuff) = cmd & 0xFF;
	*(txPckBuff+1) = data & 0xFF;
	*(txPckBuff+2) = 0;
	*(txPckBuff+3) = 0;
}

void codingRspPck16(uint16_t data, uint8_t cmd) {
	*(txPckBuff) = cmd & 0xFF;
	*(txPckBuff+1) = data & 0xFF;
	*(txPckBuff+2) = (data >> 8) & 0xFF;
	*(txPckBuff+3) = 0;
}

void codingRspPck32(uint32_t data, uint8_t cmd) {
	*(txPckBuff) = cmd & 0xFF;
	*(txPckBuff+1) = data & 0xFF;
	*(txPckBuff+2) = (data >> 8) & 0xFF;
	*(txPckBuff+3) = (data >> 16) & 0xFF;
}


/* инициализация портов в/в */
void initIO(void){
	/* Настприваем на ВЫХОД порт к которым подклчен ИП для ШД */
	sbi(SM_DDR, SM_EN);

	/* Настприваем на ВЫХОД порты к которым подклчен двигатель */
	sbi(SM_DDR, SM_WIRE_1);
	sbi(SM_DDR, SM_WIRE_2);
	sbi(SM_DDR, SM_WIRE_3);
	sbi(SM_DDR, SM_WIRE_4);

	stopSM();

	/* Настриваем на ВЫХОД порт для меандра  */
	// sbi(MEANDER_DDR, MEANDER); 
}


// настройка прерывания от внешнего источник (кнопки)
void initExtInt0(){
	// срабатывание по низкому уровню на выводе INT0
	cbi(MCUCR, ISC00);
	cbi(MCUCR, ISC01);
	// резрещаем внешние прерывания
	sbi(GICR, INT0);
}


// Запуск ТС1 
void turnOnTC1(){
	isBlockTC1 = true;
	// разрешаем прерывания при переполнении
	sbi(TIMSK, TOIE1);

	// устанавливаем делитель частоты 64
	sbi(TCCR1B, CS10);
	sbi(TCCR1B, CS11);
	cbi(TCCR1B, CS12);
	
	// устанавливаем нормальный режим
	// в этом режиме OCR1A нельзя изменить, OCR1A = 0xFFFF
	cbi(TCCR1A, WGM10);
	cbi(TCCR1A, WGM11);
	cbi(TCCR1B, WGM12);
	cbi(TCCR1B, WGM13);

	// подстраиваим частоту срабатываения
	TCNT1 = TCNT1_SM_FORVARD_MOVE;
}

//Отключаем ТС1
void turnOffTC1(){
	cli();
	// выключение таймера
	cbi(TCCR1B, CS10);
	cbi(TCCR1B, CS11);
	cbi(TCCR1B, CS12);

	stopSM();

	pcCommand = DO_STOP_SM;
	isBlockTC1 = false;
	sei();
}


// Проверка расположения (парковки) ШД в исходном (начальном) положении 
// Обратный ход ШД до закрытия окна опто-прерывателя
bool checkSMInBeginPos(){
	cli();

	while (opto_intrpt_is_closed()){
		for (int8_t i = 3; i >= 0; --i){
			SM_PORT = smTableNormalStep[i] | _BV(SM_EN);
			_delay_ms(SM_DELAY_STEP_MS);
			ind_led_msr_state(true, true, LED_BLINK_MEDIUM);
			if (opto_intrpt_is_closed()) continue;
		}
	}

	stopSM();
	ind_led_msr_state(false, false, 0);
	sei();
	return true;
}

// остановка ШД - снятия напряжения с управляющих выводов
// отключение ИП для ШД
void stopSM(){
	cbi(SM_PORT, SM_EN);
	cbi(SM_PORT, SM_WIRE_1);
	cbi(SM_PORT, SM_WIRE_2);
	cbi(SM_PORT, SM_WIRE_3);
	cbi(SM_PORT, SM_WIRE_4);
}

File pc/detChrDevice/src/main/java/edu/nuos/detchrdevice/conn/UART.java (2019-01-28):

package edu.nuos.detchrdevice.conn;

import edu.nuos.detchrdevice.app.Const;
import edu.nuos.detchrdevice.gui.UI;
import edu.nuos.detchrdevice.gui.UIEntry;
import jssc.SerialPort;
import jssc.SerialPortEvent;
import jssc.SerialPortEventListener;
import jssc.SerialPortException;


/**
 * Управление COM портом
 */
public class UART {

	/**
	 * Обратный вызов для GUI.
	 */
	private CallbackUI callbackUI;
	private SerialPort serialPort;
	private UIEntry uiEntry;

	/**
	 * Временный буфер при приеме данных с COM порта
	 */
	private int[] rxDataBuff;

	/**
	 * Флаг обнаружения устройства
	 * true - устройство опознано
	 */
	private boolean isDeviceFound = false;

	/**
	 * Счетчик правильно полученных символов в секции данных при инициализации устройства .
	 * Если все символы совпадают - это устройство инициализировано.
	 * Если же нет - на открытом COM порту другое устройство.
	 */
	private int responseCount = 0;

	// Принятые команда и данные от сервера.
	private int cmd, data;



	public UART(UIEntry uiEntry) {
		this.uiEntry = uiEntry;
		callbackUI = uiEntry;
	}

	/**
	 * Автоподключение к ком порту устройства.
	 * Выполняеться полный перебор всех портов в ОС. Далее каждый открытый порт
	 * проверяеться на пренадлежность к устройству, т.к. к ОС может быть подключено
	 * несколько устройств.
	 */
	public String deviceComPortAutoConnect() {
		for (String port : Const.COM_PORTS) {
			boolean isPortOpen = uartInit(port);
			if (isPortOpen) {
				identDevice();
				try {
					Thread.sleep(300);
				} catch (InterruptedException e) {
					e.printStackTrace();
				}
				if (isDeviceFound()) {

					return port;
				}
			}
			try {
				Thread.sleep(75);
			} catch (InterruptedException e) {
				e.printStackTrace();
			}
		}
		return null;
	}

	/**
	 * Инициализация COM порта.
	 * @param portName имя COM порта (например com1, ttyACM0)
	 * @return true - порт открыт
	 */
	public boolean uartInit(String portName){
		System.out.println("portName = " + portName);
		serialPort = new SerialPort(portName);
		try {
			serialPort.openPort();
			serialPort.setParams(SerialPort.BAUDRATE_9600,
					SerialPort.DATABITS_8,
					SerialPort.STOPBITS_1,
					SerialPort.PARITY_NONE);
			//Включаем аппаратное управление потоком (для FT232 нжуно отключать)
//            serialPort.setFlowControlMode(SerialPort.FLOWCONTROL_RTSCTS_IN |
//                                          SerialPort.FLOWCONTROL_RTSCTS_OUT);
			serialPort.addEventListener(new PortReader(), SerialPort.MASK_RXCHAR);
			System.out.println("port open.");
			return true;
		}
		catch (SerialPortException ex) {
//			System.out.println(ex);
//			JOptionPane.showMessageDialog(null, "Port is close !", "Warning", JOptionPane.WARNING_MESSAGE);
			System.out.println("port " + portName + " close");
		}
		return false;
	}

	/**
	 * Попытка связи с устройством на заданном COM порту.
	 * @return true - устройство опознано
	 */
	public boolean identDevice() {
		tryInitDeviceRequest();
		return isDeviceFound;
	}

	/**
	 * Обработчик данных получаемых данных от COM порта.
	 * Метод {@link edu.nuos.detchrdevice.conn.UART.PortReader#serialEvent(SerialPortEvent)}
	 * срабатывает при получении данных от COM порта.
	 */
	private class PortReader implements SerialPortEventListener {
		@Override
		public void serialEvent(SerialPortEvent event) {
			synchronized(event){
				if(event.isRXCHAR() && event.getEventValue() > 0){
					if (isDeviceFound) {
						decoder();
					} else {
						tryInitDeviceResponse();
					}
				}
			}
		}
	}


	/**
	 * Расшифровует принятый пакет на команды и данные.
	 */
	private void decoder() {
		try {
			rxDataBuff = serialPort.readIntArray(Const.RX_BUFF_SIZE);

			cmd = (rxDataBuff[0] & 0xFF);

			switch (cmd) {
				case Const.CMD_MAKING_MSR:
					data = rxDataBuff[1] & 0xFF;
					callbackUI.addAdcVal(data);
//					System.out.println("making msr, data=" + data);
					callbackUI.setServerStatus(UI.ServerStatus.MAKING_MSR);
					break;

				case Const.CMD_STOP_MSR:
					System.out.println("stop msr");
					callbackUI.setServerStatus(UI.ServerStatus.MSR_IS_MANUAL_INTERRUPTED);
					break;

				case Const.CMD_MAKING_PARKING:
					System.out.println("Make parking ...");
					callbackUI.blockUI(true);
					callbackUI.setServerStatus(UI.ServerStatus.PARKING);
					break;

				case Const.CMD_STOP_PARKING:
					System.out.println("Parking is done.");
					callbackUI.blockUI(false);
					callbackUI.setServerStatus(UI.ServerStatus.STAND_BY);
					break;
			}

		} catch (SerialPortException e) {
			e.printStackTrace();
		}
	}

	/**
	 * Выполнение попытки нахождения устройства.
	 * Запрос к устройству.
	 */
	private void tryInitDeviceRequest() {
		try {
			serialPort.writeIntArray(new int[]{Const.CMD_INIT_DEVICE, 0, 0, 0});
		} catch (SerialPortException e) {
			e.printStackTrace();
		}
	}

	/**
	 * Выполнение попытки нахождения устройства.
	 * Проверка ответа от устройства.
	 */
	private void tryInitDeviceResponse() {
		try {
			rxDataBuff = serialPort.readIntArray(Const.RX_BUFF_SIZE);
			boolean rightInitCmd = false;

			System.out.println("RX arr:");
			for (int rxCh : rxDataBuff) {
				System.out.println("rxCh = " + rxCh);

				if (rxCh == Const.CMD_INIT_DEVICE) {
					rightInitCmd = true;
					continue;
				}

				if (rightInitCmd && rxCh == Const.RESPONSE_INIT_DEVICE[responseCount]) {
					responseCount++;
				}
			}
		} catch (SerialPortException e) {
			e.printStackTrace();
		}

		if (responseCount == Const.RESPONSE_INIT_DEVICE.length) {
			System.out.println("Device found !");
			callbackUI.setServerStatus(UI.ServerStatus.STAND_BY);
			isDeviceFound = true;
			responseCount = 0;
		}
	}

	/**
	 * Write request package to server
	 *
	 * @param pck package writes to port
	 */
	public void writeRqPck(int[] pck) {
		try {
			serialPort.writeIntArray(pck);
		} catch (SerialPortException e) {
			e.printStackTrace();
		}
	}

	/**
	 * Этот интерфейс должен реализовать тот класс, который
	 * будет обрабатвыать получаемые результаты от COM порта устройства.
	 */
	public interface CallbackUI {
		/**
		 * Метод должен вызываться при получении с COM порта данных.
		 *
		 * @param val значение
		 */
		void addAdcVal(int val);

		/**
		 * Блокирование элеменотов GUI при выполнении определенных действий со стороны сервера.
		 *
		 * @param makeBlock true - выполнить блокировку, false - разблокировать
		 */
		void blockUI(boolean makeBlock);

		/**
		 * Установка статуса сервера.
		 * Позволяет отобразить состояние сервера в каждый момент времени.
		 *
		 * @param status статус
		 */
		void setServerStatus(UI.ServerStatus status);
	}

	public SerialPort getSerialPort() {
		return serialPort;
	}

	public boolean isDeviceFound() {
		return isDeviceFound;
	}
}

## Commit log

2015-12-10 Рабочий вариант прошивки v 1.0
2015-12-10 ДОбавлен пустой проект для пк
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2015-12-10 Modified gitignore. Add kicad circuit part.
    [determOfchromiumOxideDevice.kicad_pcb, determOfchromiumOxideDevice.sch]
2015-12-10 На схеме: добавлено описание какой Ку нужно установить, изменены номиналы R для ОУ, изменен номинал С3. Исправлена ошибка монтажа - были перепутаны usb data которые идут на tn2313, D+ был не туда под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
    [determOfchromiumOxideDevice.kicad_pcb, determOfchromiumOxideDevice.sch]
2015-12-10 Modified circuit and export to png.
    [determOfchromiumOxideDevice.sch]
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2015-12-14 Убраны не используемые ui компоненты: кнопка clear и textarea.
2015-12-14 Изменено кол-во точек графика ф-ии одновременно выводимых на одном экране.
2015-12-14 ДОбавлен простой функционал для записи полученных резульататов измерения в файл с именем даты и время. В файл пишуться только значения ацп. Запись происходит только когда после запуска процесса польз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
2015-12-14 Убраны неиспользуемый код. Предназначался для тестирования отправки строки в приложение перед началом запуска измерений.
2015-12-14 В приложение и mcu добавлен механизм иденитификации устройства. Если ком порт открыт то выполнеться попытка установления связи между приложением и устройством. Приложение инициирует сеанс идентификац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
2015-12-15 В этом коммите добавлен функционал для автоматического определения com порта устройства. Если com порт найден - выполняеться подключение, если нет - com порт остаеться по умол. - com1. И соответствен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
2015-12-15 Если при автоопределении не удалось обнаружить устройство - выводиться информационное сообщение в модальном окне. Также добавлен вывод модального окна при ручном выборе ком порта.
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2015-12-15 Перед стартом каждого нового измерения стираеться предыдущий график.
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2015-12-16 В этом коммите ИСПРАВЛЕНА случайно стертая строка вызова метода записи в файл. Это исправление касаеться предыдущего комита. НО запись в файл тут работает только при нажатии на кнопку Стоп.
    [UIEntry.java]
2015-12-16 Этот коммит вводит синхронизацию между количеством шагов и еденицами измерения длины образца в мм. Значения ацп передаються в приложение каждые 0.2 мм при перемещении каретки (червяка). Это позволяет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
2015-12-16 При сохранеиии в файл добавляються такие данные в столбцах: номер точки, значения длины образца, напряжение в 8 битной сетке .
2015-12-16 Изменено условие инициализации ком порта для лучшей читаемости.
2015-12-16 Рефакторинг. Переименнованы некоторые переменные, добавлены комментарии, немного изменен код в обработчике кнопки СтартСтоп.
2015-12-16 Метод deviceComPortAutoConnect перенесен в класс UART. Добавлен сброс всех переменных отвечающих за процесс записи при старте нового измерения образца.
2015-12-16 Функционал для записи результатов в файл перенесен в новый класс.
2015-12-16 В названиях подписей к столбцам при сохранении в файл запятые изменены на скобки т.к. например в libreoffice calc запятые являються разделителями включенными по умолчанию.
2015-12-16 Добавлена возможность изменения масштаба по оси Y .
2015-12-17 Добавлены подписи к осям x и y . Цвета примененные на графике вынесены в константы.
2015-12-17 Уменьшено количество буфера для отображения точек на экране и при записи. Изменены параметры сигнатуры класса для записи данных в файл.
2015-12-17 Убран код NumberFormat. При этом между написью оси y и самой осью появилось свободное место. До этого надпись почти сливалась с осью.
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2015-12-18 Изменение протокола передачиданных между устройством и пприложением. Промежуточный вариант. На стороне мк переписаниы ф-ии отправки данных. Добавлены дополнительные комментарии к ф-ии ининициализации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
2016-03-09 Изменен регистр константы RESPONSE_INIT_DEVICE для отправки команд в приложение. Команды и данные теперь отправляются в прерывании таймера 0. Это нужно для асинхронной передайчи байт на ПК в приложен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
2016-09-07 Additional materials.
    [TC calculations.ods, Список примененных элементов.xlsx]
2018-10-19 Changed input photo signal part in schematic - added RV and emitter repeater cascade in LM324. Changed amp gain.Important - input part in LM324 in schematic do not match from PCB layout.
    [determOfchromiumOxideDevice.sch]
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2018-10-19 Added image opto-interrupter image, renamed some files in etc dir.
    [TC_calculations.ods]
2018-10-19 Redesign schematic - input amp, interface in FT232, step motor driver in MOSFET-s. Full repaint schematic in KiCAD 5.
    [determOfchromiumOxideDevice.kicad_pcb, determOfchromiumOxideDevice.sch, powerUnit.sch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]
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2018-10-20 Fix bug in schematic - added connection SM enable from DC-DC convertor to MCU.
    [surfaceActivationScanner.sch]
2018-10-25 In powerUnit.sch changed 15uHn to 15uH.
    [powerUnit.sch]
2018-10-25 Performed tracing PCB: dimmednsions 95 x 70 mm, double sided board.
    [surfaceActivationScanner.kicad_pcb]
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2018-11-28 Added articles for some components in powerUnit schematic.
    [powerUnit.sch]
2018-11-28 Added articles for some components in main schematic.
    [surfaceActivationScanner.sch]
2018-11-28 Changed gitignore file - expand KiCad ignore files. Added delimiters between sections.
2018-11-29 Firmware. Added support power supply for step motor (SM). Changed programmer and port in Makefile.
2018-11-29 Firmware. Refactoring. Changed all full types to short.
    [main.c]
2018-11-29 Firmware. Refactoring. Moved uart part to single module.
2018-11-29 Firmware. Refactoring. Moved adc part to single module.
2018-11-30 Firmware. Remove not used blinkled funct-s. Make process led indication.
2018-12-10 Firmware. Refactoring. Opto interrupter handler move to single module. Added blink led support when caret is parking to home position.
2018-12-10 Firmware. Refactoring. Removed not used timer2 handler for generate meander.
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2018-12-12 App. Fix to prev commit.
    [UIEntry.java]
2018-12-13 App. Changes Y axis and their minor and major interval.
    In Y axis change max value to 100 percents. And change label name.
2018-12-13 Firmware. Fix. Changed adc sync coefficient.
    This coeff determined number of steps to skip before sending the ADC
    value from the light sensor.
    In this coeff tested - sending ~300 adc values from 60 mm length of
    sample. In chart in full length of sample can view 60 mm in X axis.
    See issue #32 .
    [main.c]
2019-01-24 Firmware. Fix. Sometimes not responsed mcu to app in init process. This chnages does not affect anything. Button start-stop in device(server) do not work.
    [main.c]
